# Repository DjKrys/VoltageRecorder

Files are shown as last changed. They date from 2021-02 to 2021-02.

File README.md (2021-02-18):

<p align="center">
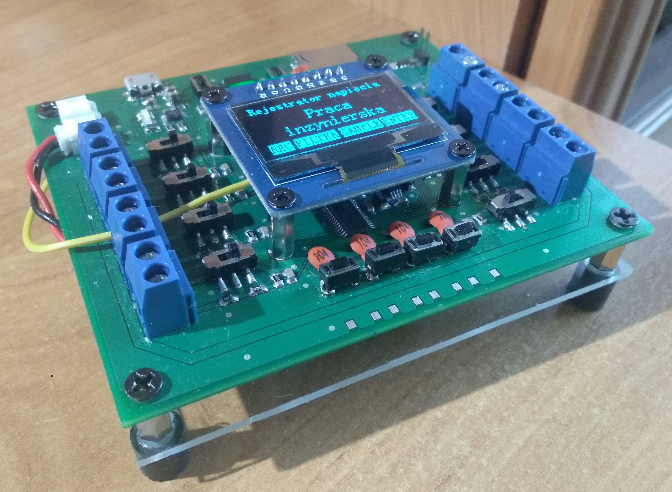
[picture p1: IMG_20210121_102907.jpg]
  
</p>

# VoltageRecorder
Celem projektu było zaprojektowanie, montaż i uruchomienie wielokanałowego rejestratora danych do precyzyjnego pomiaru napięcia(The aim of the project was to design, assemble and launch Multi-channel data logger for precise voltage measurement). My engineer's thesis.

# Cel i zakres pracy
Celem pracy jest zaprojektowanie oraz budowa rejestratora do precyzyjnego pomiaru napięcia o zasilaniu bateryjnym. Urządzenie to musi pozwolić na szybką archiwizację danych oraz zapisanie ich w postaci cyfrowej na nieulotną pamięć FLASH. Zbieranie i rejestracja danych na nośnik pamięci o odpowiedniej pojemności pozwala ponadto na prowadzenie wielogodzinnych pomiarów. Aby osiągnąć cel został wykonany schemat elektryczny urządzenia, a następnie na jego podstawie wykonana płytka PCB. Drugim krokiem będzie stworzenie algorytmu w języku C, w celu obsługi podzespołów oraz zarządzania danymi. Zostanie stworzony prosty interfejs użytkownika umożliwiający ustawienie parametrów archiwizacji (ilość próbek na sekundę, zakres pomiarowy), prezentację wyników oraz kalibracje urządzenia.
Ostatnim krokiem była doświadczalna weryfikacja działania układu oraz próba określenia uzyskanych parametrów.

# Założenia
* Urządzenie zasilane z akumulatorka (z pełną jego obsługą, czyli ładowarką + monitoringiem stanu naładowania)
* Pomiary napięcia w ośmiu kanałach analogowych
* Zapis pomiarów do pliku na kartę SD wraz z interwałami czasowymi
* Wyświetlanie informacji na wyświetlaczu
* Projekt płytki PCB oraz montaż 
* Testowe oprogramowanie

# Weryfikacja działania
https://drive.google.com/file/d/1y4KWzrLdbeENvkOfH9YcUIEn7dakh6ji/view?usp=sharing

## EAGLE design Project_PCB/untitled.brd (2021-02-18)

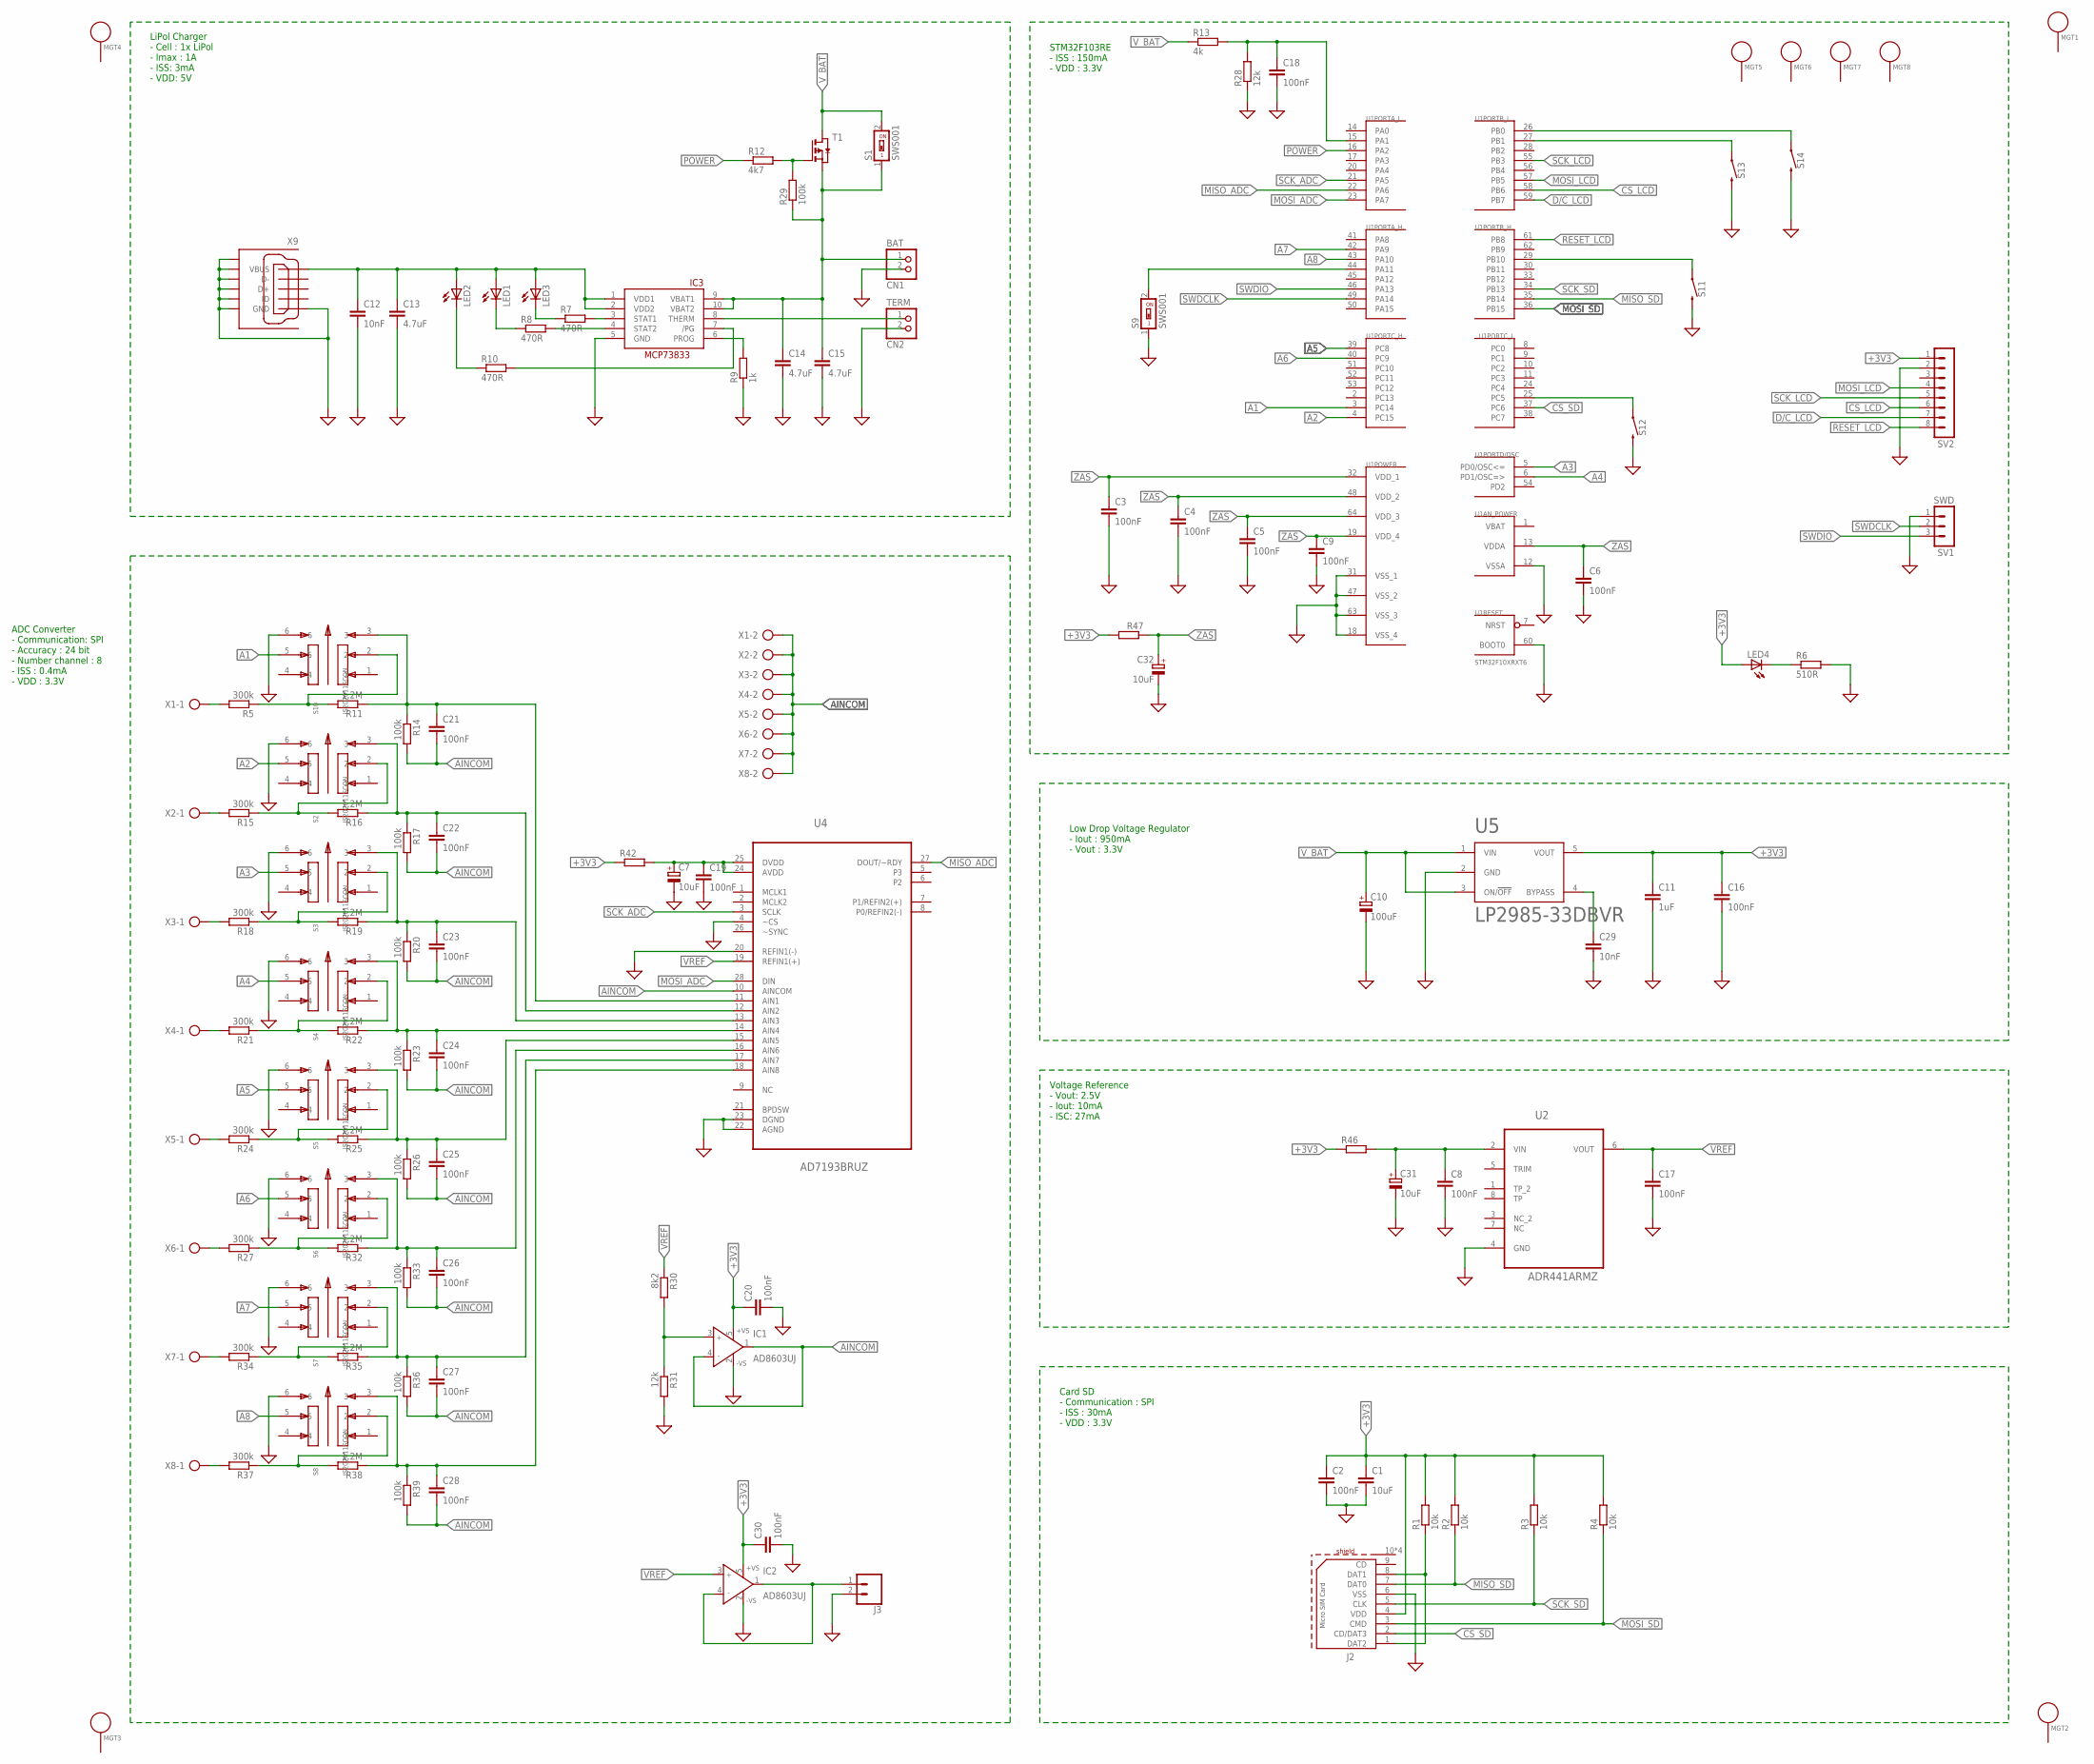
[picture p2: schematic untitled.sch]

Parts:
C1: 10uF; C0805
C2, C3, C4, C5, C6, C8, C9, C16, C17, C18, C19, C20, C21, C22, C23, C24, C25, C26, C27, C28, C30: 100nF; C0805
C7, C31, C32: 10uF; SMC_B
C10: 100uF; SMC_B
C11: 1uF; C0805
C12, C29: 10nF; C0805
C13, C14, C15: 4.7uF; C0805
CN1: BAT; JST-PH-2-THM-RA
CN2: TERM; JST-PH-2-THM-RA
IC1, IC2: AD8603UJ; SOT23-5
IC3: MCP73833-UN; MSOP10
J2: 693071020811
J3: CONN_02PTH3; 1X02_LONGPADS
LED1, LED2, LED3, LED4: LEDCHIP-LED0805; CHIP-LED0805
MGT1, MGT2, MGT3, MGT4, MGT5, MGT6, MGT7, MGT8: MOUNTING_HOLE; BEAGLEBONEBLACK_MOUNTING_HOLE
R1, R2, R3, R4: 10k; R0805
R5, R15, R18, R21, R24, R27, R34, R37: 300k; R0805
R6: 510R; R0805
R7, R8, R10: 470R; R0805
R9: 1k; R0805
R11, R16, R19, R22, R25, R32, R35, R38: 1.2M; R0805
R12: 4k7; R0805
R13: 4k; R0805
R14, R17, R20, R23, R26, R29, R33, R36, R39: 100k; R0805
R28, R31: 12k; R0805
R30: 8k2; R0805
R42, R46, R47: R-EU_R1206; R1206
S1, S9: SWS001; SMS-001
S2, S3, S4, S5, S6, S7, S8, S10: JS202011SCQN; SW_JS202011SCQN
S11, S12, S13, S14: MOMENTARY-SWITCH-SPST-SMD-6.2MM-TALL; TACTILE_SWITCH_SMD_6.2MM_TALL
SV1: SWD; MA03-1
SV2: MA08-1
T1: PMOSSOT223; SOT223
U1: STM32F10XRXT6; TQFP64
U2: ADR441ARMZ; SOP65P490X110-8N
U4: AD7193BRUZ; SOP65P640X120-28N
U5: LP2985-33DBVR; SOT-23-5
X1, X2, X3, X4, X5, X6, X7, X8: AK300/2
X9: GHI-CONNECTORS_10118192-0001LF; GHI-CONNECTORS_10118192-0001LF(MICRO-USB-B-AMPHENOL-FCI)

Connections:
+3V3: C1.1, C2.1, C11.1, C16.1, C20.1, C30.1, IC1.5 (+VS), IC2.5 (+VS), J2.4 (VDD), LED4.A, R1.2, R2.2, R3.2, R4.2, R42.1, R46.1, R47.2, SV2.1, U5.5 (VOUT)
A1: S10.5, U1.3 (PC14)
A2: S2.5, U1.4 (PC15)
A3: S3.5, U1.5 (PD0/OSC<=)
A4: S4.5, U1.6 (PD1/OSC=>)
A5: S5.5, U1.39 (PC8)
A6: S6.5, U1.40 (PC9)
A7: S7.5, U1.42 (PA9)
A8: S8.5, U1.43 (PA10)
AINCOM: C21.2, C22.2, C23.2, C24.2, C25.2, C26.2, C27.2, C28.2, IC1.1 (OUT), IC1.4 (IN-), R14.2, R17.2, R20.2, R23.2, R26.2, R33.2, R36.2, R39.2, U4.10 (AINCOM), X1.2, X2.2, X3.2, X4.2, X5.2, X6.2, X7.2, X8.2
CS_LCD: SV2.6, U1.58 (PB6)
CS_SD: J2.2 (CD/DAT3), U1.37 (PC6)
D/C_LCD: SV2.7, U1.59 (PB7)
GND: C1.2, C2.2, C3.2, C4.2, C5.2, C6.2, C7.-, C8.2, C9.2, C10.-, C11.2, C12.2, C13.2, C14.2, C15.2, C16.2, C17.2, C18.2, C19.2, C20.2, C29.2, C30.2, C31.-, C32.-, CN1.2 (1), CN2.2 (1), IC1.2 (-VS), IC2.2 (-VS), IC3.5 (GND), J2.6 (VSS), J3.2, R6.2, R9.1, R28.1, R31.2, S2.6, S3.6, S4.6, S5.6, S6.6, S7.6, S8.6, S9.1, S10.6, S11.B2 (2), S12.B2 (2), S13.B2 (2), S14.B2 (2), SV1.1, SV2.2, U1.12 (VSSA), U1.18 (VSS_4), U1.31 (VSS_1), U1.47 (VSS_2), U1.60 (BOOT0), U1.63 (VSS_3), U2.4 (GND), U4.4 (~CS), U4.20 (REFIN1(-)), U4.22 (AGND), U4.23 (DGND), U5.2 (GND), X9.CGND1 (SGND1), X9.CGND2 (SGND2), X9.CGND3 (SGND3), X9.CGND4 (SGND4), X9.CGND5 (SGND5), X9.CGND6 (SGND6), X9.GND
MISO_ADC: U1.22 (PA6), U4.27 (DOUT/~RDY)
MISO_SD: J2.7 (DAT0), R2.1, U1.35 (PB14)
MOSI_ADC: U1.23 (PA7), U4.28 (DIN)
MOSI_LCD: SV2.4, U1.57 (PB5)
MOSI_SD: J2.3 (CMD), R4.1, U1.36 (PB15)
unnamed: J2.1 (DAT2), J2.8 (DAT1), R1.1
unnamed: LED4.C, R6.1
unnamed: C22.1, R16.1, R17.1, S2.3, U4.12 (AIN2)
unnamed: R5.2, X1.1
unnamed: IC3.3 (STAT1), R7.2
unnamed: IC3.6 (PROG), R9.2
unnamed: IC3.7 (/PG), R10.2
unnamed: LED3.C, R7.1
unnamed: LED1.C, R8.1
unnamed: IC3.4 (STAT2), R8.2
unnamed: LED2.C, R10.1
unnamed: CN2.1 (2), IC3.8 (THERM)
unnamed: C12.1, C13.1, IC3.1 (VDD1), IC3.2 (VDD2), LED1.A, LED2.A, LED3.A, X9.VBUS
unnamed: C21.1, R11.1, R14.1, S10.3, U4.11 (AIN1)
unnamed: R15.1, R16.2, S2.2
unnamed: C29.1, U5.4 (BYPASS)
unnamed: R5.1, R11.2, S10.2
unnamed: R21.1, R22.2, S4.2
unnamed: C26.1, R32.1, R33.1, S6.3, U4.16 (AIN6)
unnamed: C27.1, R35.1, R36.1, S7.3, U4.17 (AIN7)
unnamed: R15.2, X2.1
unnamed: C18.1, R13.2, R28.2, U1.15 (PA1)
unnamed: C23.1, R19.1, R20.1, S3.3, U4.13 (AIN3)
unnamed: IC2.1 (OUT), IC2.4 (IN-), J3.1
unnamed: C7.+, C19.1, R42.2, U4.24 (AVDD), U4.25 (DVDD)
unnamed: R18.2, X3.1
unnamed: C14.1, C15.1, CN1.1 (2), IC3.9 (VBAT1), IC3.10 (VBAT2), R29.1, S1.1, T1.3 (S)
unnamed: R18.1, R19.2, S3.2
unnamed: IC1.3 (IN+), R30.2, R31.1
unnamed: S11.A2 (1), U1.29 (PB10)
unnamed: C24.1, R22.1, R23.1, S4.3, U4.14 (AIN4)
unnamed: C25.1, R25.1, R26.1, S5.3, U4.15 (AIN5)
unnamed: R21.2, X4.1
unnamed: S14.A2 (1), U1.26 (PB0)
unnamed: R24.2, X5.1
unnamed: R24.1, R25.2, S5.2
unnamed: S13.A2 (1), U1.27 (PB1)
unnamed: R12.2, R29.2, T1.1 (G)
unnamed: S9.2, U1.44 (PA11)
unnamed: R27.2, X6.1
unnamed: R27.1, R32.2, S6.2
unnamed: S12.A2 (1), U1.25 (PC5)
unnamed: R34.2, X7.1
unnamed: R34.1, R35.2, S7.2
unnamed: C28.1, R38.1, R39.1, S8.3, U4.18 (AIN8)
unnamed: R37.2, X8.1
unnamed: R37.1, R38.2, S8.2
unnamed: C8.1, C31.+, R46.2, U2.2 (VIN)
POWER: R12.1, U1.16 (PA2)
RESET_LCD: SV2.8, U1.61 (PB8)
SCK_ADC: U1.21 (PA5), U4.3 (SCLK)
SCK_LCD: SV2.5, U1.55 (PB3)
SCK_SD: J2.5 (CLK), R3.1, U1.34 (PB13)
SWDCLK: SV1.2, U1.49 (PA14)
SWDIO: SV1.3, U1.46 (PA13)
VBAT: U1.1 (VBAT)
VREF: C17.1, IC2.3 (IN+), R30.1, U2.6 (VOUT), U4.19 (REFIN1(+))
V_BAT: C10.+, R13.1, S1.2, T1.2 (D), T1.4 (D), U5.1 (VIN), U5.3 (ON/!OFF!)
ZAS: C3.1, C4.1, C5.1, C6.1, C9.1, C32.+, R47.1, U1.13 (VDDA), U1.19 (VDD_4), U1.32 (VDD_1), U1.48 (VDD_2), U1.64 (VDD_3)

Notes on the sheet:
LiPol Charger - Cell : 1x LiPol - Imax : 1A - ISS: 3mA - VDD: 5V
ADC Converter - Communication: SPI - Accuracy : 24 bit - Number channel : 8 - ISS : 0.4mA - VDD : 3.3V
Card SD - Communication : SPI - ISS : 30mA - VDD : 3.3V
STM32F103RE - ISS : 150mA - VDD : 3.3V
Low Drop Voltage Regulator - Iout : 950mA - Vout : 3.3V
Voltage Reference - Vout: 2.5V - Iout: 10mA - ISC: 27mA

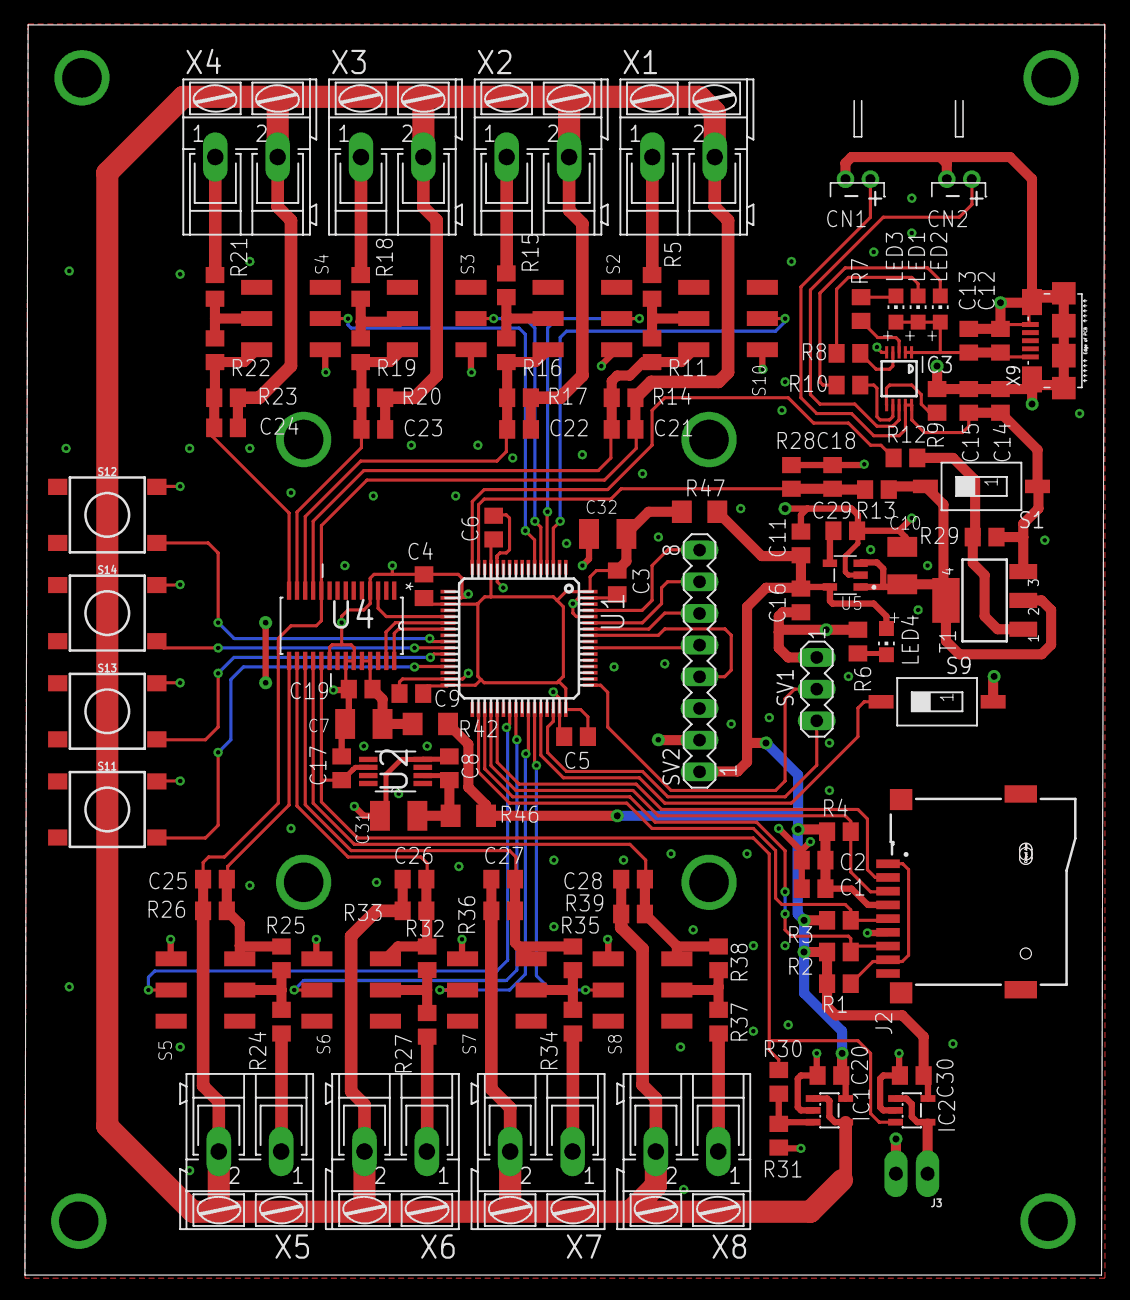
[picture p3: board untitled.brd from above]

Board: 2 copper layers, 86.6 x 100.3 mm, 123 parts (0 on the bottom side), 77 nets.

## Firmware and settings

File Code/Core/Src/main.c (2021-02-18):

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
/* Includes ------------------------------------------------------------------*/
#include "main.h"
#include "adc.h"
#include "dma.h"
#include "fatfs.h"
#include "spi.h"
#include "tim.h"
#include "gpio.h"

#include "SD_card.h"
#include "OLED.h"
#include "AD7193.h"

/* USER CODE BEGIN Includes */

#define DIVIDER_4x 4.0
#define DIVIDER_16x 16.18

int stateB1 = 0;
int stateB2 = 0;
int stateB3 = 0;
int stateB4 = 0;
int button = 0;
int32_t next = 0;
float time = 0.0;

int Channel1, Channel2, Channel3, Channel4, Channel5, Channel6, Channel7, Channel8 = 0;
float divider1, divider2, divider3, divider4, divider5, divider6, divider7, divider8 = 0.0;
float Pomiar1, Pomiar2, Pomiar3, Pomiar4, Pomiar5, Pomiar6, Pomiar7, Pomiar8 = 0.0;

int RECORD_BOOL = 0; // 1 - Nagrywanie, 0 - Brak nagrywania
int SD_Error = 1;
int Filter = 2;			// 1 - Filtr z tlumieniem 50Hz, 2 - Filtr bez tlumienia
uint32_t PomiarADC;
float Vsense;
int ProcentBattery;

const float SupplyVoltage = 3.36; // [Volts]
const float ADCResolution = 4096.0;
const float ADCBatteryRange = 0.5;
const float ADCBatteryMin = 2.6;

/* USER CODE END Includes */


void SystemClock_Config(void);
/**
  * @brief  The application entry point.
  * @retval int
  */
int main(void)
{
  /* MCU Configuration--------------------------------------------------------*/

  /* Reset of all peripherals, Initializes the Flash interface and the Systick. */
  HAL_Init();

  /* Configure the system clock */
  SystemClock_Config();

  /* Initialize all configured peripherals */
  MX_GPIO_Init();
  MX_DMA_Init();
  MX_ADC1_Init();
  MX_SPI1_Init();
  MX_SPI2_Init();
  MX_SPI3_Init();
  MX_TIM6_Init();
  MX_TIM7_Init();
  MX_FATFS_Init();
  /* USER CODE BEGIN 2 */
	
	////////////OLED////////////
	OLED_Init();
	
	OLED_Full_screen();
	HAL_Delay(1000);
	OLED_Clear_screen();
	OLED_Power_on();
	HAL_Delay(1000);
	OLED_Start();
	HAL_Delay(3000);

///////////Przyciski
	HAL_NVIC_EnableIRQ(EXTI0_IRQn);
	HAL_NVIC_EnableIRQ(EXTI1_IRQn);
	HAL_NVIC_EnableIRQ(EXTI2_IRQn);
	HAL_NVIC_EnableIRQ(EXTI9_5_IRQn);
	HAL_NVIC_EnableIRQ(EXTI15_10_IRQn);

	//////////VBAT////////
	HAL_ADC_Start_DMA(&hadc1, &PomiarADC, 1);

////////////ADC////////////
	AppendStatusValuetoData();
	SetPGAGain(1);
	SetAveraging(96);
	SetFilterSinc3();
	SetPsuedoDifferentialInputs();
	Calibrate();
	ReadRegisterMap();

  /* USER CODE END 2 */

  /* Infinite loop */
  /* USER CODE BEGIN WHILE */
  while (1)
  {
		 /* USER CODE END WHILE */
		
		if(HAL_GPIO_ReadPin(GPIOC, GPIO_PIN_14) == 1)
			divider1 = DIVIDER_16x;
		else
			divider1 = DIVIDER_4x;
		
		if(HAL_GPIO_ReadPin(GPIOC, GPIO_PIN_15) == 1)
			divider2 = DIVIDER_16x;
		else
			divider2 = DIVIDER_4x;
		
		if(HAL_GPIO_ReadPin(GPIOD, GPIO_PIN_0) == 1)
			divider3 = DIVIDER_16x;
		else
			divider3 = DIVIDER_4x;
		
		if(HAL_GPIO_ReadPin(GPIOD, GPIO_PIN_1) == 1)
			divider4 = DIVIDER_16x;
		else
			divider4 = DIVIDER_4x;
		
		if(HAL_GPIO_ReadPin(GPIOC, GPIO_PIN_8) == 1)
			divider5 = DIVIDER_16x;
		else
			divider5 = DIVIDER_4x;
		
		if(HAL_GPIO_ReadPin(GPIOC, GPIO_PIN_9) == 1)
			divider6 = DIVIDER_16x;
		else
			divider6 = DIVIDER_4x;
		
		if(HAL_GPIO_ReadPin(GPIOA, GPIO_PIN_14) == 1)
			divider7 = DIVIDER_16x;
		else
			divider7 = DIVIDER_4x;
		
		if(HAL_GPIO_ReadPin(GPIOA, GPIO_PIN_10) == 1)
			divider8 = DIVIDER_16x;
		else
			divider8 = DIVIDER_4x;
		
		if(Channel1 == 1)
			Pomiar1 = DataToVoltage(ReadADCChannel(0) >> 8);
		if(Channel2 == 1)
			Pomiar2 = DataToVoltage(ReadADCChannel(1) >> 8);
		if(Channel3 == 1)
			Pomiar3 = DataToVoltage(ReadADCChannel(2) >> 8);
		if(Channel4 == 1)
			Pomiar4 = DataToVoltage(ReadADCChannel(3) >> 8);
		if(Channel5 == 1)
			Pomiar5 = DataToVoltage(ReadADCChannel(4) >> 8);
		if(Channel6 == 1)
			Pomiar6 = DataToVoltage(ReadADCChannel(5) >> 8);	
		if(Channel7 == 1)		
			Pomiar7 = DataToVoltage(ReadADCChannel(6) >> 8);
		if(Channel8 == 1)
			Pomiar8 = DataToVoltage(ReadADCChannel(7) >> 8);
    /* USER CODE BEGIN 3 */
  }
  /* USER CODE END 3 */
}

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
/* USER CODE BEGIN 4 */
void HAL_TIM_PeriodElapsedCallback(TIM_HandleTypeDef *htim)
{
	if(htim->Instance == TIM6)
	{
		Vsense = (SupplyVoltage*PomiarADC)/(ADCResolution);
		ProcentBattery = (int)(((Vsense-ADCBatteryMin)/ADCBatteryRange)*100);
		if(ProcentBattery < 3)
			HAL_GPIO_WritePin(GPIOA, GPIO_PIN_2, GPIO_PIN_SET);

		OLED_Display_measurement(ProcentBattery, RECORD_BOOL, Pomiar1*divider1, Pomiar2*divider2, Pomiar3*divider3, Pomiar4*divider4, Pomiar5*divider5, Pomiar6*divider6, Pomiar7*divider7, Pomiar8*divider8);
	}
	
	if(htim->Instance == TIM7)
	{
		next++;
		write_SD(Pomiar1*divider1, Pomiar2*divider2, Pomiar3*divider3, Pomiar4*divider4, Pomiar5*divider5, Pomiar6*divider6, Pomiar7*divider7, Pomiar8*divider8, time*next);
	}
}

void HAL_GPIO_EXTI_Callback(uint16_t GPIO_Pin)
{
	//////B1////////////
	if(GPIO_Pin == GPIO_PIN_5)
	{
		button = 1;
		HAL_TIM_Base_Stop_IT(&htim6);
		stateB1++;
		
		if(stateB1 > 3)
			stateB1 = 1;
		
		OLED_Top(stateB1);
	}
	///////////B2//////////
	if(GPIO_Pin == GPIO_PIN_0)
	{
		button = 2;
		stateB2++;
		
		if(stateB2 > 2)
			stateB2 = 1;
				
    OLED_Select_Filter(stateB2);
	}
		
	///////////////B3//////////
	if(GPIO_Pin == GPIO_PIN_1)
	{
		button = 3;
		stateB3++;
		
		if(stateB3 > 8)
			stateB3 = 1;
				
		if(Filter == 1)
			OLED_Sampling_frequency1(stateB3);
		else if(Filter == 2)
			OLED_Sampling_frequency2(stateB3);
	}

/////////B4////////
	if(GPIO_Pin == GPIO_PIN_11)
	{
		button = 4;
		HAL_TIM_Base_Stop_IT(&htim6);
		
		stateB4++;
		
		if(stateB4 > 10)
			stateB4 = 1;
		
		OLED_ON_OFF_Channel(stateB4);

	}
	
/////////ENTER/////////
	if(GPIO_Pin == GPIO_PIN_2)
	{
		switch(button)
		{
			case 1:
				switch(stateB1)
				{
					case 1:
							if(Init_SD() != 1)
							{
								open_SD();
								write_info();
								time = ((float)(PERIOD_Tim + 1.0))/1000.0;
								RECORD_BOOL = 1;
								HAL_TIM_Base_Start_IT(&htim6);
								HAL_TIM_Base_Start_IT(&htim7);
								SD_Error = 0;
							}
							else
							{
								SD_Error = 1;
								OLED_Error();
							}
						break;
					case 2:
							if(close_SD() || SD_Error != 1)
							{
								RECORD_BOOL = 0;
								HAL_TIM_Base_Stop_IT(&htim6);
								HAL_TIM_Base_Stop_IT(&htim7);
								next = 0;
								OLED_Succesfull();
							}
							else
								OLED_Error();
						break;
					case 3:
							HAL_TIM_Base_Start_IT(&htim6);
						break;
				}
				break;
				
			case 2:
				switch(stateB2)
				{
					case 1:
							SetAveraging(96);
							Filter = 1;
							OLED_Succesfull();
						break;
					case 2:
							SetAveraging(24);
							Filter = 2;
							OLED_Succesfull();
						break;
				}
				break;
				
			case 3:
				if(Filter == 1)
				{
					switch(stateB3)
					{
						case 1:
								PERIOD_Tim = 59;
								OLED_Succesfull();
							break;
						case 2:
								PERIOD_Tim = 99;
								OLED_Succesfull();
							break;
						case 3:
								PERIOD_Tim = 249;
								OLED_Succesfull();
							break;
						case 4:
								PERIOD_Tim = 499;
								OLED_Succesfull();
							break;
						case 5:
								PERIOD_Tim = 999;
								OLED_Succesfull();
							break;
						case 6:
								PERIOD_Tim = 1999;
								OLED_Succesfull();
							break;
						case 7:
								PERIOD_Tim = 4999;
								OLED_Succesfull();
							break;
						case 8:
								PERIOD_Tim = 9999;
								OLED_Succesfull();
							break;
					}
					MX_TIM7_Init();
				}
				if (Filter == 2)
				{
					switch(stateB3)
					{
						case 1:
								PERIOD_Tim = 14;
								OLED_Succesfull();
							break;
						case 2:
								PERIOD_Tim = 49;
								OLED_Succesfull();
							break;
						case 3:
								PERIOD_Tim = 149;
								OLED_Succesfull();
							break;
						case 4:
								PERIOD_Tim = 249;
								OLED_Succesfull();
							break;
						case 5:
								PERIOD_Tim = 499;
								OLED_Succesfull();
							break;
						case 6:
								PERIOD_Tim = 999;
								OLED_Succesfull();
							break;
						case 7:
								PERIOD_Tim = 1999;
								OLED_Succesfull();
							break;
						case 8:
								PERIOD_Tim = 4999;
								OLED_Succesfull();
							break;
					}
					MX_TIM7_Init();
				}
				break;
			
			case 4:	
				switch(stateB4)
				{
					case 1:
							HAL_TIM_Base_Stop_IT(&htim6);
							OLED_Clear_screen();
						break;
					case 2:
							if(Channel1 == 0)
							{
								Channel1 = 1;
								OLED_Activate();
							}
							else
							{
								Channel1 = 0;
								OLED_Deactivate();
							}
						break;
					case 3:
							if(Channel2 == 0)
							{
								Channel2 = 1;
								OLED_Activate();
							}
							else
							{
								Channel2 = 0;
								OLED_Deactivate();
							}
						break;
					case 4:
							if(Channel3 == 0)
							{
								Channel3 = 1;
								OLED_Activate();
							}
							else
							{
								Channel3 = 0;
								OLED_Deactivate();
							}
						break;
					case 5:
							if(Channel4 == 0)
							{
								Channel4 = 1;
								OLED_Activate();
							}
							else
							{
								Channel4 = 0;
								OLED_Deactivate();
							}
						break;
					case 6:
						HAL_GPIO_WritePin(GPIOA, GPIO_PIN_2, GPIO_PIN_SET);
						break;
					case 7:
							if(Channel5 == 0)
							{
								Channel5 = 1;
								OLED_Activate();
							}
							else
							{
								Channel5 = 0;
								OLED_Deactivate();
							}
						break;
					case 8:
							if(Channel6 == 0)
							{
								Channel6 = 1;
								OLED_Activate();
							}
							else
							{
								Channel6 = 0;
								OLED_Deactivate();
							}
						break;
					case 9:
							if(Channel7 == 0)
							{
								Channel7 = 1;
								OLED_Activate();
							}
							else
							{
								Channel7 = 0;
								OLED_Deactivate();
							}
						break;
					case 10:
							if(Channel8 == 0)
							{
								Channel8 = 1;
								OLED_Activate();
							}
							else
							{
								Channel8 = 0;
								OLED_Deactivate();
							}
						break;
				}
				break;
		}
	}
}

void EXTI9_5_IRQHandler(void)
{
	HAL_GPIO_EXTI_IRQHandler(GPIO_PIN_5);
}

void EXTI0_IRQHandler(void)
{
	HAL_GPIO_EXTI_IRQHandler(GPIO_PIN_0);
}

void EXTI1_IRQHandler(void)
{
	HAL_GPIO_EXTI_IRQHandler(GPIO_PIN_1);
}

void EXTI15_10_IRQHandler(void)
{
	HAL_GPIO_EXTI_IRQHandler(GPIO_PIN_11);
}

void EXTI2_IRQHandler(void)
{
	HAL_GPIO_EXTI_IRQHandler(GPIO_PIN_2);
}

/* USER CODE END 4 */
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


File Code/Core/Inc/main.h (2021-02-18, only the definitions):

#define A1_Pin GPIO_PIN_14
#define A1_GPIO_Port GPIOC
#define A2_Pin GPIO_PIN_15
#define A2_GPIO_Port GPIOC
#define A3_Pin GPIO_PIN_0
#define A3_GPIO_Port GPIOD
#define A4_Pin GPIO_PIN_1
#define A4_GPIO_Port GPIOD
#define POWER_Pin GPIO_PIN_2
#define POWER_GPIO_Port GPIOA
#define B1_Pin GPIO_PIN_5
#define B1_GPIO_Port GPIOC
#define B2_Pin GPIO_PIN_0
#define B2_GPIO_Port GPIOB
#define B3_Pin GPIO_PIN_1
#define B3_GPIO_Port GPIOB
#define B4_Pin GPIO_PIN_2
#define B4_GPIO_Port GPIOB
#define CS_SD_Pin GPIO_PIN_6
#define CS_SD_GPIO_Port GPIOC
#define A5_Pin GPIO_PIN_8
#define A5_GPIO_Port GPIOC
#define A6_Pin GPIO_PIN_9
#define A6_GPIO_Port GPIOC
#define A7_Pin GPIO_PIN_9
#define A7_GPIO_Port GPIOA
#define A8_Pin GPIO_PIN_10
#define A8_GPIO_Port GPIOA
#define REC_Pin GPIO_PIN_11
#define REC_GPIO_Port GPIOA
#define CS_LCD_Pin GPIO_PIN_6
#define CS_LCD_GPIO_Port GPIOB
#define D_C_LCD_Pin GPIO_PIN_7
#define D_C_LCD_GPIO_Port GPIOB
#define RESET_LCD_Pin GPIO_PIN_8
#define RESET_LCD_GPIO_Port GPIOB

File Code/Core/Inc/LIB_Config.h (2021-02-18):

/**
  ******************************************************************************
  * @file    LIB_Config.h
  * @author  Waveshare Team
  * @version 
  * @date    13-October-2014
  * @brief     This file provides configurations for low layer hardware libraries.
  ******************************************************************************
  * @attention
  *
  * THE PRESENT FIRMWARE WHICH IS FOR GUIDANCE ONLY AIMS AT PROVIDING CUSTOMERS
  * WITH CODING INFORMATION REGARDING THEIR PRODUCTS IN ORDER FOR THEM TO SAVE
  * TIME. AS A RESULT, WAVESHARE SHALL NOT BE HELD LIABLE FOR ANY
  * DIRECT, INDIRECT OR CONSEQUENTIAL DAMAGES WITH RESPECT TO ANY CLAIMS ARISING
  * FROM THE CONTENT OF SUCH FIRMWARE AND/OR THE USE MADE BY CUSTOMERS OF THE
  * CODING INFORMATION CONTAINED HEREIN IN CONNECTION WITH THEIR PRODUCTS.
  *
  ******************************************************************************
  */

/* Define to prevent recursive inclusion -------------------------------------*/
#ifndef _USE_LIB_CONFIG_H_
#define _USE_LIB_CONFIG_H_
//Macro Definition

/* Includes ------------------------------------------------------------------*/
#include "stm32f1xx_hal.h"
#include "MacroAndConst.h"
#include "SSD1306.h"
#include "Fonts.h"

extern SPI_HandleTypeDef hspi3;

#define SH1106

#define INTERFACE_4WIRE_SPI     //4-wire SPI 


#define SSD1306_CS_PIN          GPIO_PIN_6
#define SSD1306_RES_PIN         GPIO_PIN_8
#define SSD1306_DC_PIN          GPIO_PIN_7

#define SSD1306_CS_GPIO         GPIOB
#define SSD1306_RES_GPIO        GPIOB
#define SSD1306_DC_GPIO         GPIOB 

#define __SSD1306_CS_SET()      HAL_GPIO_WritePin(SSD1306_CS_GPIO, SSD1306_CS_PIN, GPIO_PIN_SET)
#define __SSD1306_CS_CLR()      HAL_GPIO_WritePin(SSD1306_CS_GPIO, SSD1306_CS_PIN, GPIO_PIN_RESET)

#define __SSD1306_RES_SET()     HAL_GPIO_WritePin(SSD1306_RES_GPIO, SSD1306_RES_PIN, GPIO_PIN_SET)
#define __SSD1306_RES_CLR()     HAL_GPIO_WritePin(SSD1306_RES_GPIO, SSD1306_RES_PIN, GPIO_PIN_RESET)

#define __SSD1306_DC_SET()      HAL_GPIO_WritePin(SSD1306_DC_GPIO, SSD1306_DC_PIN, GPIO_PIN_SET)
#define __SSD1306_DC_CLR()      HAL_GPIO_WritePin(SSD1306_DC_GPIO, SSD1306_DC_PIN, GPIO_PIN_RESET)

#define SSD1331_SCLK_PIN        GPIO_PIN_3
#define SSD1331_SDIN_PIN        GPIO_PIN_5
      
#define SSD1331_SCLK_GPIO       GPIOB
#define SSD1331_SDIN_GPIO       GPIOB

#define __SSD1306_CLK_SET()     GPIO_WriteBit(SSD1306_CLK_GPIO, SSD1306_CLK_PIN, Bit_SET)
#define __SSD1306_CLK_CLR()     GPIO_WriteBit(SSD1306_CLK_GPIO, SSD1306_CLK_PIN, Bit_RESET)

#define __SSD1306_WRITE_BYTE(DATA)  while(HAL_SPI_Transmit(&hspi3,DATA,1,0x10) != HAL_OK)


#endif

/*-------------------------------END OF FILE-------------------------------*/

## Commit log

2021-02-18 Add schematic and project PCB
    [untitled.brd, untitled.sch]
2021-02-18 Add descritpion device

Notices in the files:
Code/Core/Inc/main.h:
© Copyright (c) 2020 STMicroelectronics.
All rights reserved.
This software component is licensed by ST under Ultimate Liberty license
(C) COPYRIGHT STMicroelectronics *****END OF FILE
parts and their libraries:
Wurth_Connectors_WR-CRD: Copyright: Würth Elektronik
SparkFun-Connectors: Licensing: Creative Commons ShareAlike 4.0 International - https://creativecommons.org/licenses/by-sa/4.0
